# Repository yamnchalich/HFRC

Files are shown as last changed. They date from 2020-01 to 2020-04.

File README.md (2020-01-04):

# HFRC
High Frame Rate Camera Project developed using the free Vivado WebPACK version 2017.4.1. 
Compatible with a MicroZed 7020 SoC + FMC Carrier Board + PMOD attachments (VGA, switches, and pushbuttons) + custom daughter PCB containing the PYTHON 1300 monochrome image sensor.

Can operate in the following configurations:

| Resolution | Framerates | Record Time (s) (8-bit pixels, ~1 GB storage) |
| --- | --- | --- |
| 1280x1024 (SXGA)  | 211 (MAX) | 3.86 |
| | 100 | 8.14 |
| | 60 | 13.57 |
| | 30 | 27.13 |
| 640x480 (VGA) | 817 (MAX) | 4.25 |
| | 400 | 8.69 |
| 256x256 | 2329 (MAX) | 6.99 |
| | 1000 | 16.29 |  

FMC Carrier Board voltage should be set to 2.5 V and set MicroZed to boot from SD card.

Assumes SD Card for boot and storing pics/vids.

Requires separate download of Xilinx XAPP1017 from the Xilinx website as you must agree separately 
to the terms of use of the design license agreement for the application.

Once downloaded, add the delay_controller_wrap.v and serdes_1_to_10_idelay_ddr.v file to the Verilog_macros folder before running the tcl script. Modify line 419 of serdes_1_to_10_idelay_ddr to:

assign rx_data[10*i+j] = dataout[10*i+9-j] ; //EDITED TO GIVE REVERSE BIT ORDER

Open Vivado, cd to the directory containing these files and run "source HFRC.tcl" in the tcl command window.
After creating the project, generate the bitstream, export the hardware to the SDK and open the SDK.
In the SDK, create a FSBL with a standalone OS platform and new BSP, and an empty C project to import the TestSD.c file.
Create the boot image by adding the files (in order): zynq fsbl elf file, the hardware bit file, and the C code elf.
Put boot image onto an SD card and you are good to go.

See the user guide pdf for information on operating the camera assuming the appropriate hardware.

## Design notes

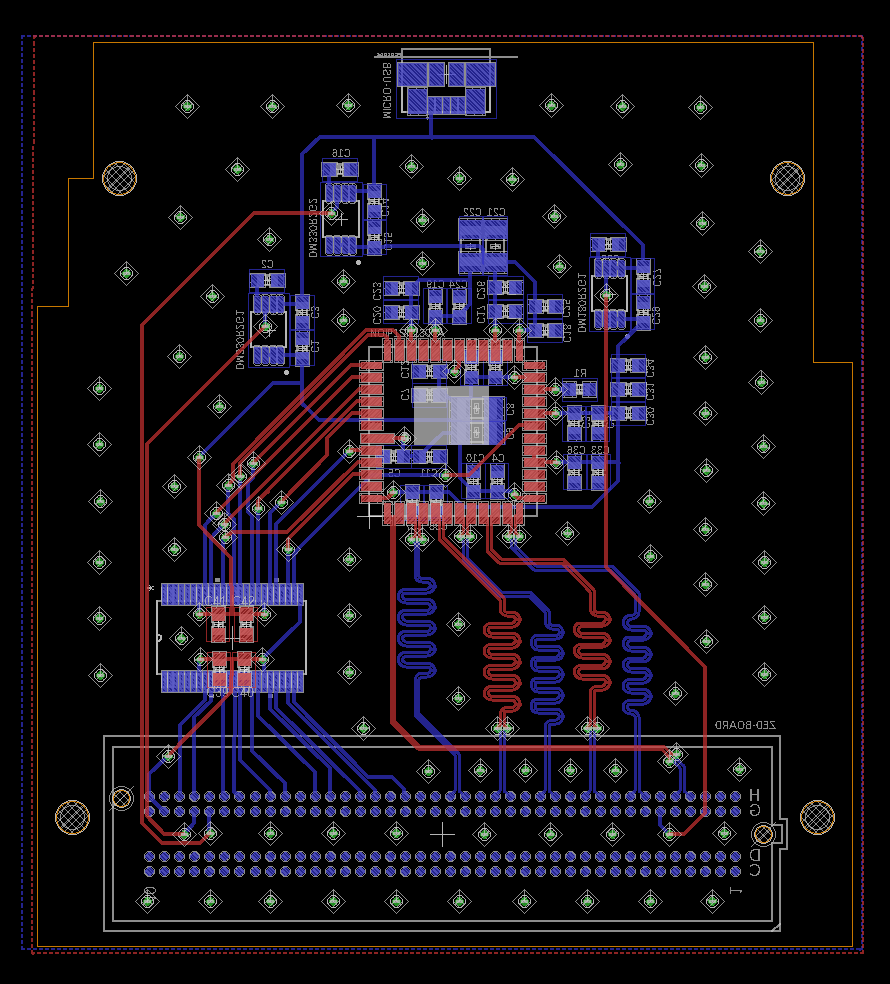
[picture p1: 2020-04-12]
PCB/board_design_image.png

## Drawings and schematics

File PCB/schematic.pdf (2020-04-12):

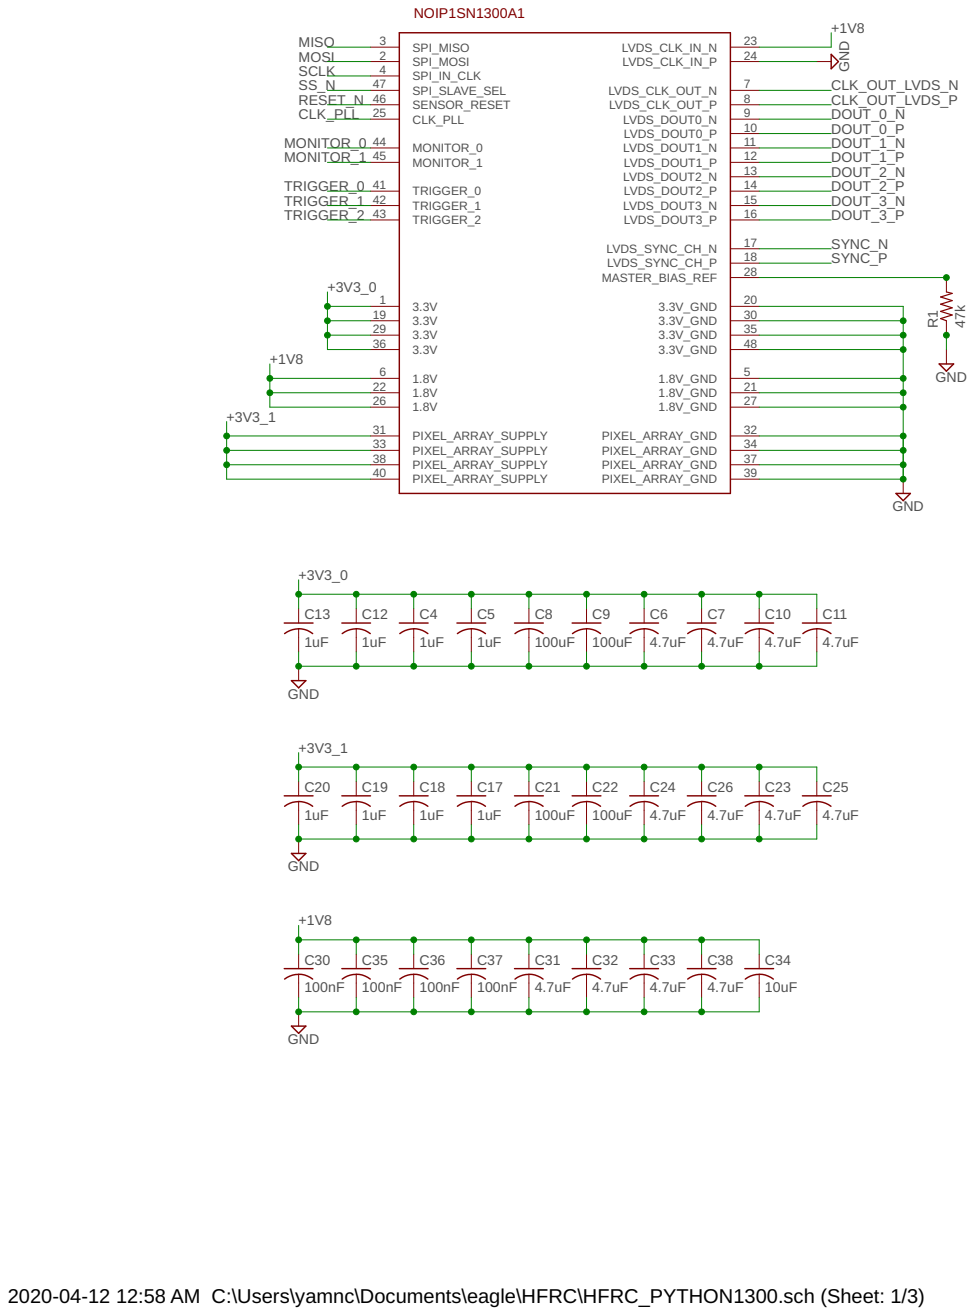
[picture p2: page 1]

19 | 30
29 | 35
36 | 48

2020-04-12 12:58 AM C:\Users\yamnc\Documents\eagle\HFRC\HFRC_PYTHON1300.sch (Sheet: 1/3)

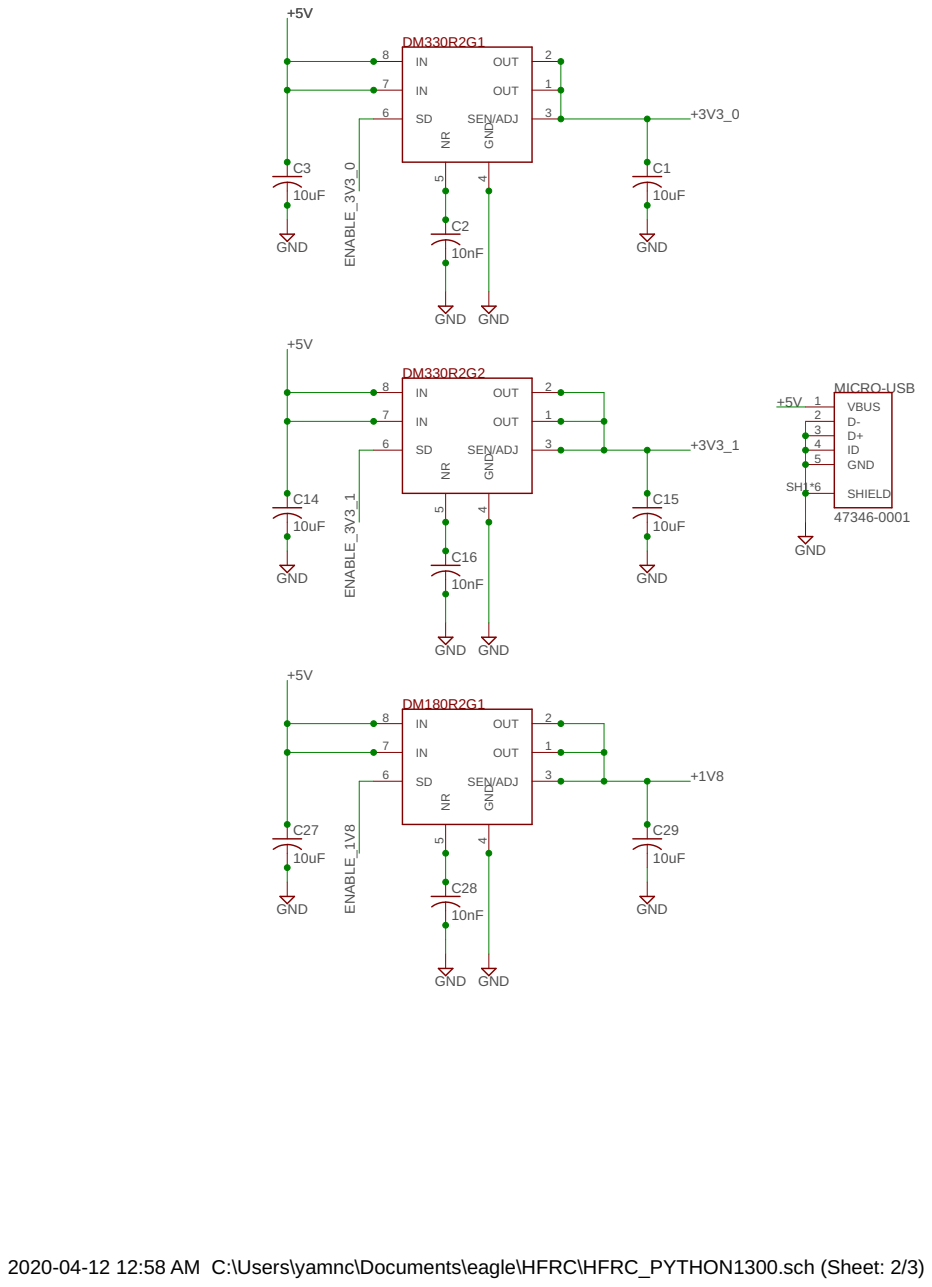
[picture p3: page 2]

2020-04-12 12:58 AM C:\Users\yamnc\Documents\eagle\HFRC\HFRC_PYTHON1300.sch (Sheet: 2/3)

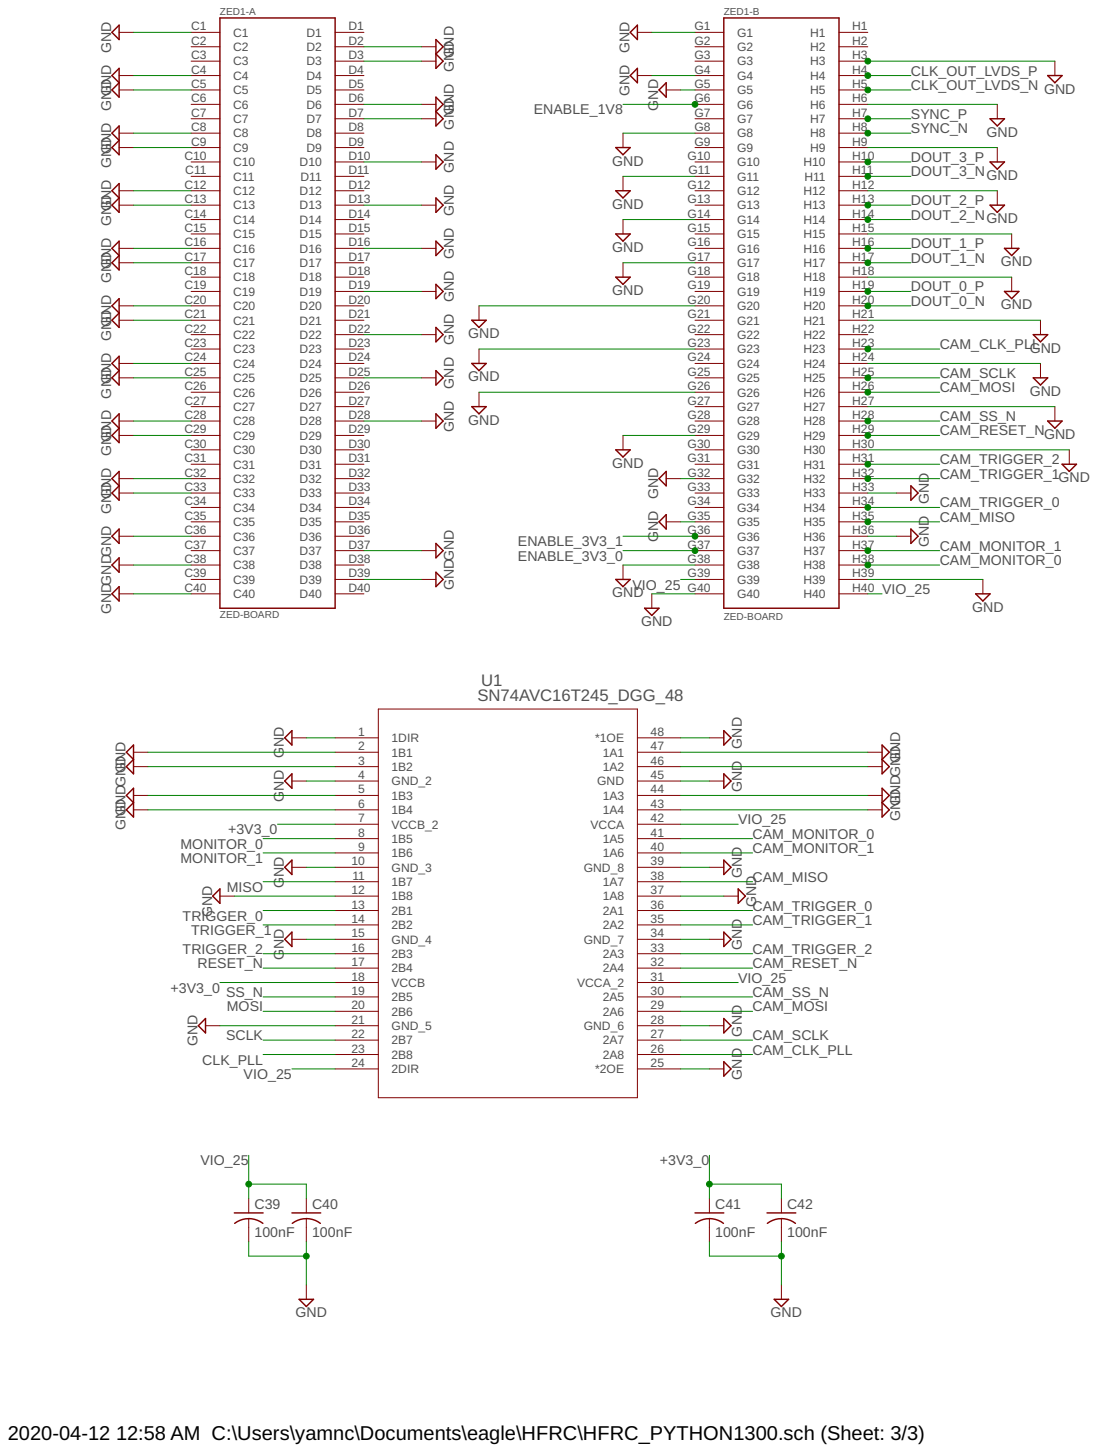
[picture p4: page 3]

GND GND GND GND GND GND GND GND GND GND

GND GND GND GND GND GND GND GND GND GND GND GND GND

GND GND

2020-04-12 12:58 AM C:\Users\yamnc\Documents\eagle\HFRC\HFRC_PYTHON1300.sch (Sheet: 3/3)

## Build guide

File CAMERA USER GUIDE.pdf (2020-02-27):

# CAMERA USER GUIDE

Sensor | PYTHON 1300
Type | CMOS
Default res/fps | 1280x1024 at 211 fps
Pixel size | 4.8 micron
Shutter Type | Global
ADC | 10 bit (recorded at 8 bit)
Colour | Greyscale
Power | ~ 4 W
Price | ~$650 USD for prototype

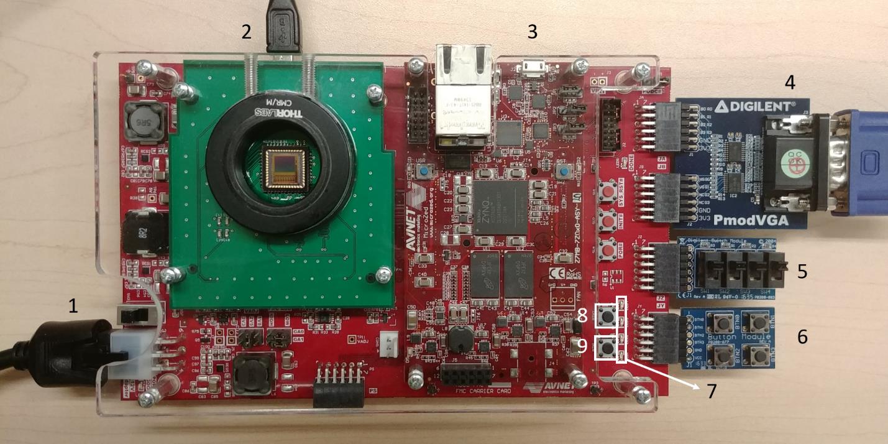
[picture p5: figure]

Number | Name | Description
1 | Carrier board power supply | Supplies power to all components except the camera sensor. V_ADJ set to 2.5 V.
2 | Camera sensor power supply | Supplies power to the camera sensor.
3 | SD Card | Used for boot and for permanent storage of pics/vids.
4 | VGA output | VGA output connection for real-time display of frames on a monitor.
5 | Switches (SW) | Switches controlling resolution/fps and camera reset.
6 | Pushbuttons (PB) | Pushbuttons to take pictures and videos and store them in the RAM.
7 | Red LEDs (LED) | Red LED lights that indicate recording and storage status.
8 | VGA toggle (VT) | Flips VGA output between greyscale and artificial colour.
9 | Storage toggle (ST) | Used to alter the function of some of the PBs to transfer pics/vids from RAM to the SD Card.

The system mounts onto a microscope through a C-mount adapter and is operated fully through the onboard switches and pushbuttons. Pictures and videos are stored on the SD Card in .pgm and .bin formats, respectfully. Video binary files can be processed into individual frames using the supplied convert application and converted into video using FFmpeg software.

### Switches (SW)

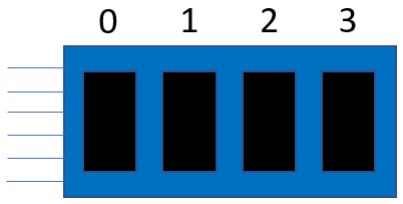
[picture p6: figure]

SW[0:2] | Configuration
000 | 1280x1024, 211 fps
001 | 1280x1024, 100 fps
011 | 1280x1024, 60 fps
010 | 1280x1024, 30 fps
100 | 640x480, 817 fps
101 | 640x480, 400 fps
110 | 256x256, 2329 fps
111 | 256x256, 1000 fps

By default, SW[3] acts as a high reset. When set low, the camera undergoes the power up sequence in the configuration set by SW[0:2]. Setting the reset high again during operation initiates the soft power down sequence for the camera and acts as a global reset.
The configuration can be changed during this reset period.

**It is recommended that turning off the camera is done by first setting SW[3] high to initiate the power down sequence of the camera, wait about one second, and then turn off the carrier board power.

### Pushbuttons (PB)

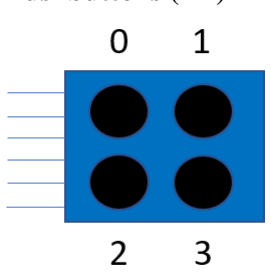
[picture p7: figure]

Pressing PB1 takes a photo and pressing PB3 carries out a video capture. PB2 can be used to put the camera in a continuous recording mode, where pressing it again stops the recording. The last few seconds (duration dependent on configuration) is stored. Once the pictures and videos have been captured and

## 0: unused 1: take photo 2: start/stop continuous recording 3: take video

stored in RAM, pressing ST changes the function of PB1 and PB3 to now transfer the picture or video, respectively, into the SD Card for long term storage.

Resolution | Framerates | Record Time (s) (8-bit pixels, ~1 GB storage)
1280x1024 (SXGA) | 211 (MAX) 100 60 30 | 3.86 8.14 13.57 27.13
640x480 (VGA) | 817 (MAX) 400 | 4.25 8.69
256x256 | 2329 (MAX) 1000 | 6.99 16.29

### Red LED lights (LED)

### VGA

The VGA port can output 4-bits of R, G, and B, which can produce 2⁽⁴⁺⁴⁺⁴⁾ = 4096 different colours, but since the camera outputs in greyscale, we must feed 4-bits of each pixel into all the RGB channels resulting in only 2⁴ = 16 shades of greyscale on the monitor. The pixels are stored in memory as 8-bits meaning memory dumps of images retain their quality even though the images on monitor may be poor. To compensate and add more shades on-screen, an artificial colour setting was introduced for the frames displayed on the monitor which can be enabled by button VT. Instead of black to white, it is black – violet – white, which can create less banding in the observed image.

### Post-processing

To view the pictures and even the videos later, it is recommended to download and use IrfanView. It supports many if not all the file formats and is free.

After using the convert application provided to create the frames of a video from the .bin file, download FFmpeg to create a video from the frames. It is powerful command line program for processing video and audio and can encode the frames into a video. After installation, navigate into the folder with the frames, open the cmd and use the command below:

ffmpeg -framerate 60000/1001 -f image2 -i frame_%d.pgm -vb 20M vid_60.avi

When on,

## 4: storage mode on (ST has been pressed) 3: blinks when storage (RAM to SD Card) is underway 2: unused 1: camera is continuously recording

1

2

3

4

This example translates frames frame_0, frame_1, … into a video named vid_60 in the avi file format at ~60fps and a 20M bitrate to maintain video quality. Depending on the monitor, it may not properly display 60fps so it is instead set here to 60000/1001 = 59.94 fps. You can also specify the start and end times (and set many other options) of the video if you choose to learn and become familiar with the program.

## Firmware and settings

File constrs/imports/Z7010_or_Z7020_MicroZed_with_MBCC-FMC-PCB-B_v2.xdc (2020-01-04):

# ----------------------------------------------------------------------------
#     _____
#    /     \
#   /____   \____
#  / \===\   \==/
# /___\===\___\/  AVNET ELECTRONICS MARKETING
#      \======/         www.em.avnet.com/drc
#       \====/    
# ----------------------------------------------------------------------------
# 
#  Created With Avnet Constraints Generator V0.8.0 
#     Date: Tuesday, September 02, 2014 
#     Time: 10:33:25 PM 
# 
#  This design is the property of Avnet.  Publication of this
#  design is not authorized without written consent from Avnet.
#  
#  Please direct any questions to:
#     MicroZed.org Community Forums
#     http://www.microzed.org
# 
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
# ----------------------------------------------------------------------------
# 
#  Notes: 
#
#  20 April 2015
#     IO standards based upon Bank 34 and Bank 35 (and Bank 13) Vcco supply 
#     options of 1.8V, 2.5V, or 3.3V are possible based upon the Vadj 
#     jumper (J18) settings.  By default, Vadj is expected to be set to 
#     1.8V but if a different voltage is used for a particular design, then 
#     the corresponding IO standard within this UCF should also be updated 
#     to reflect the actual Vadj jumper selection.
#
#     Net names are not allowed to contain hyphen characters '-' since this
#     is not a legal VHDL87 or Verilog character within an identifier.  
#     HDL net names are adjusted to contain no hyphen characters '-' but 
#     rather use underscore '_' characters.  Comment net name with the hyphen 
#     characters will remain in place since these are intended to match the 
#     schematic net names in order to better enable schematic search.
#
#     The string provided in the comment field provides the Zynq device pin 
#     mapping through the expansion connector to the carrier card net name
#     according to the following format:
#
#     "<Zynq Pin>.<SOM Net>.<Connector Ref>.<Connector Pin>.<Carrier Net>"
# 
# ----------------------------------------------------------------------------


# ----------------------------------------------------------------------------
# User LEDs - Bank 34
# ---------------------------------------------------------------------------- 
set_property PACKAGE_PIN R19 [get_ports {LED[0]}];  # "R19.JX1_SE_0.JX1.9.LED0"
set_property PACKAGE_PIN V13 [get_ports {LED[1]}];  # "V13.JX1_LVDS_2_N.JX1.19.LED1"

 
# ----------------------------------------------------------------------------
# One wire Security EEPROM - Bank 34
# ---------------------------------------------------------------------------- 
set_property PACKAGE_PIN T19 [get_ports {EEPROM}];  # "T19.JX1_SE_1.JX1.10.EEPROM"


# ----------------------------------------------------------------------------
# JB Pmod - Bank 34
# ---------------------------------------------------------------------------- 
set_property PACKAGE_PIN T11 [get_ports {VGA_GREEN_O[0]}];  # "T11.JX1_LVDS_0_P.JX1.11.JB0-1_P" - JB - Pin 1
set_property PACKAGE_PIN T10 [get_ports {VGA_GREEN_O[1]}];  # "T10.JX1_LVDS_0_N.JX1.13.JB0-1_N" - JB - Pin 2
set_property PACKAGE_PIN T12 [get_ports {VGA_GREEN_O[2]}];  # "T12.JX1_LVDS_1_P.JX1.12.JB2-3_P" - JB - Pin 3
set_property PACKAGE_PIN U12 [get_ports {VGA_GREEN_O[3]}];  # "U12.JX1_LVDS_1_N.JX1.14.JB2-3_N" - JB - Pin 4
set_property PACKAGE_PIN V12 [get_ports {VGA_HSYNC_O}];  # "V12.JX1_LVDS_3_P.JX1.18.JB4-5_P" - JB - Pin 7
set_property PACKAGE_PIN W13 [get_ports {VGA_VSYNC_O}];  # "W13.JX1_LVDS_3_N.JX1.20.JB4-5_N" - JB - Pin 8
set_property PACKAGE_PIN T14 [get_ports {JB6_7_P}];  # "T14.JX1_LVDS_4_P.JX1.23.JB6-7_P" - JB - Pin 9
set_property PACKAGE_PIN T15 [get_ports {JB6_7_N}];  # "T15.JX1_LVDS_4_N.JX1.25.JB6-7_N" - JB - Pin 10
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

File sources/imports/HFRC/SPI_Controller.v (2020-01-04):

/*
This module controls the configuration 
interface of the PYTHON 1300 Image Sensor
By: Yamn Chalich
*/

`timescale 1ns/100ps
/*
`ifdef DISABLE_DEFAULT_NET
`else
`default_nettype none
`endif
*/

module SPI_Controller (
	input wire reset,
	input wire SPI_START,
	
	/////// SPI
	input wire SCK,									//Serial Clock
	output logic SS_N,								//Active Low Slave select
	
	output logic MOSI,								//Serial Data To Sensor
	input wire MISO,								//Serial Data From Sensor
	
	input wire [25:0] SPI_upload_data,
	output logic [15:0] SPI_read_data,
	output reg UPLOAD_DONE
);

enum logic [2:0] {
	SPI_IDLE,
	SPI_UPLOAD_ADDRESS,
	SPI_READ_DELAY,
	SPI_READ,
	SPI_WRITE,
	SPI_WRITE_DELAY,
	SPI_SLAVE_SELECT_UP,
	SPI_DELAY
} SPI_state;

logic [25:0] SPI_upload_shift_reg;
logic [4:0] serial_counter;


// SPI control state machine
always_ff @(negedge SCK) begin
	if (reset) begin
      SPI_state <= SPI_IDLE;
		SPI_upload_shift_reg <= 26'd0;
		SPI_read_data <= 16'd0;
		serial_counter <= 5'd0;
		UPLOAD_DONE <= 1'b0;
		SS_N <= 1'b1;
	end else begin
			case (SPI_state)
			SPI_IDLE: begin
				if (SPI_START) begin
					SPI_read_data <= 16'd0;
					SPI_state <= SPI_UPLOAD_ADDRESS;
					SPI_upload_shift_reg <= {SPI_upload_data[24:0], 1'b0};
					SS_N <= 1'b0;
					
					MOSI <= SPI_upload_data[25];
					serial_counter <= serial_counter + 5'd1;
				end
			end
			SPI_UPLOAD_ADDRESS: begin
				MOSI <= SPI_upload_shift_reg[25];
				SPI_upload_shift_reg <= {SPI_upload_shift_reg[24:0], 1'b0};
				serial_counter <= serial_counter + 5'd1;
				if (serial_counter == 5'd9) begin	
					if (SPI_upload_shift_reg[25])
						SPI_state <= SPI_WRITE;
					else
						SPI_state <= SPI_READ_DELAY;
				end
			end
			SPI_READ_DELAY: begin
				//wait for data to be available on miso pin
				SPI_state <= SPI_READ;
			end
			SPI_READ: begin
				SPI_read_data <= {SPI_read_data[14:0], MISO};
				serial_counter <= serial_counter + 5'd1;
				
				if (serial_counter == 5'd26) begin
				    SPI_read_data <= SPI_read_data;
					serial_counter <= 5'd0;
					SS_N <= 1'b1;
					UPLOAD_DONE <= 1'b1;
					SPI_state <= SPI_SLAVE_SELECT_UP;
				end
			end
			SPI_WRITE: begin
				MOSI <= SPI_upload_shift_reg[25];
				SPI_upload_shift_reg <= {SPI_upload_shift_reg[24:0], 1'b0};
				serial_counter <= serial_counter + 5'd1;
				if (serial_counter == 5'd26) begin
					serial_counter <= 5'd0;
					UPLOAD_DONE <= 1'b1;
					SS_N <= 1'b1;
					SPI_state <= SPI_SLAVE_SELECT_UP;
				end
			end
			SPI_SLAVE_SELECT_UP: begin
				//pull SS_N up one clock cycle after last bit transmission
				UPLOAD_DONE <= 1'b0;
				SPI_state <= SPI_DELAY;
			end
			SPI_DELAY: begin
                //give more time between spi uploads
                SPI_state <= SPI_IDLE;
            end
		endcase
	end
end
endmodule

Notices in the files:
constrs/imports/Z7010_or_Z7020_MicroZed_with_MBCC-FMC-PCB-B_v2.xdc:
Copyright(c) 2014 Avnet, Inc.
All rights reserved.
